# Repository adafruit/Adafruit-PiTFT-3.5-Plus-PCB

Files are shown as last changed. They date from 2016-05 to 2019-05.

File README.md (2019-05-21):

## Adafruit PiTFT 3.5 Plus Display PCB
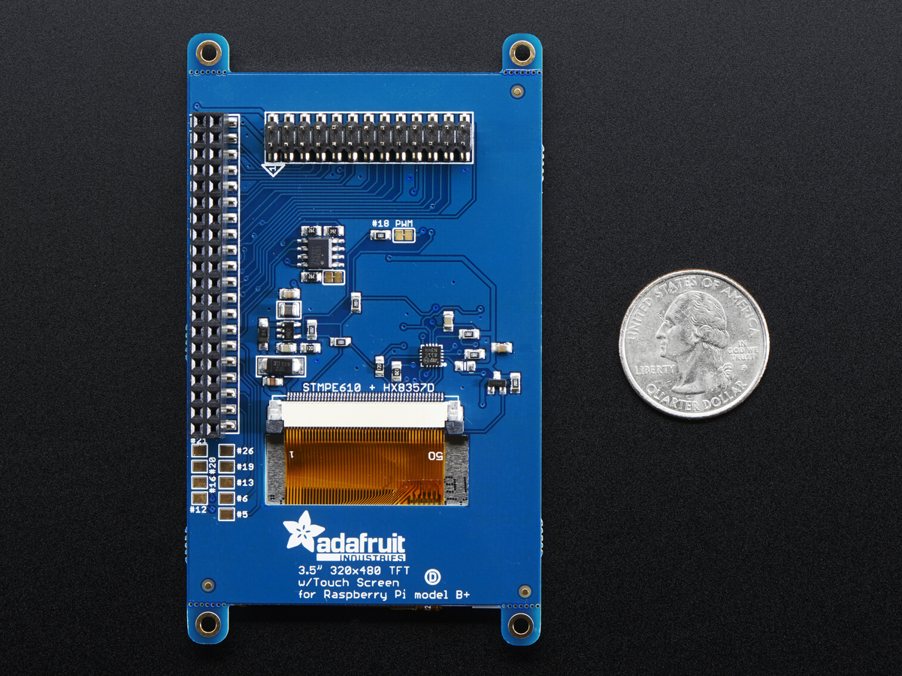
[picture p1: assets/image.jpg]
<a href="http://www.adafruit.com/products/2441"><br/>
Click here to purchase one from the Adafruit shop</a>

This display for the Raspberry Pi features a 3.5" display with 480x320 16-bit color pixels and a resistive touch overlay just like our popular original, but this one is engineered specifically to work with the newer "2x20 connector" Raspberry Pi's. The plate uses the high speed SPI interface on the Pi and can use the mini display as a console, X window port, displaying images or video etc. Best of all it plugs right in on top!

This PiTFT 3.5" is designed to fit nicely onto the Raspberry Pi Zero, Pi 3, Pi 2 or Model A+ / B+ (any Pi with a 2x20 connector). Not for use with an old Pi 1 with 2x13 connector If you'd like to use a 3.5" display with the original Pi A or Pi B, check out this version

PCB files for the Adafruit PiTFT 3.5" Plus. The format is EagleCAD schematic and board layout
- https://www.adafruit.com/product/2441

### License

Adafruit invests time and resources providing this open source design, please support Adafruit and open-source hardware by purchasing products from [Adafruit](https://www.adafruit.com)!

All text above must be included in any redistribution

Designed by Limor Fried/Ladyada for Adafruit Industries.
Creative Commons Attribution/Share-Alike, all text above must be included in any redistribution. 
See license.txt for additional information.

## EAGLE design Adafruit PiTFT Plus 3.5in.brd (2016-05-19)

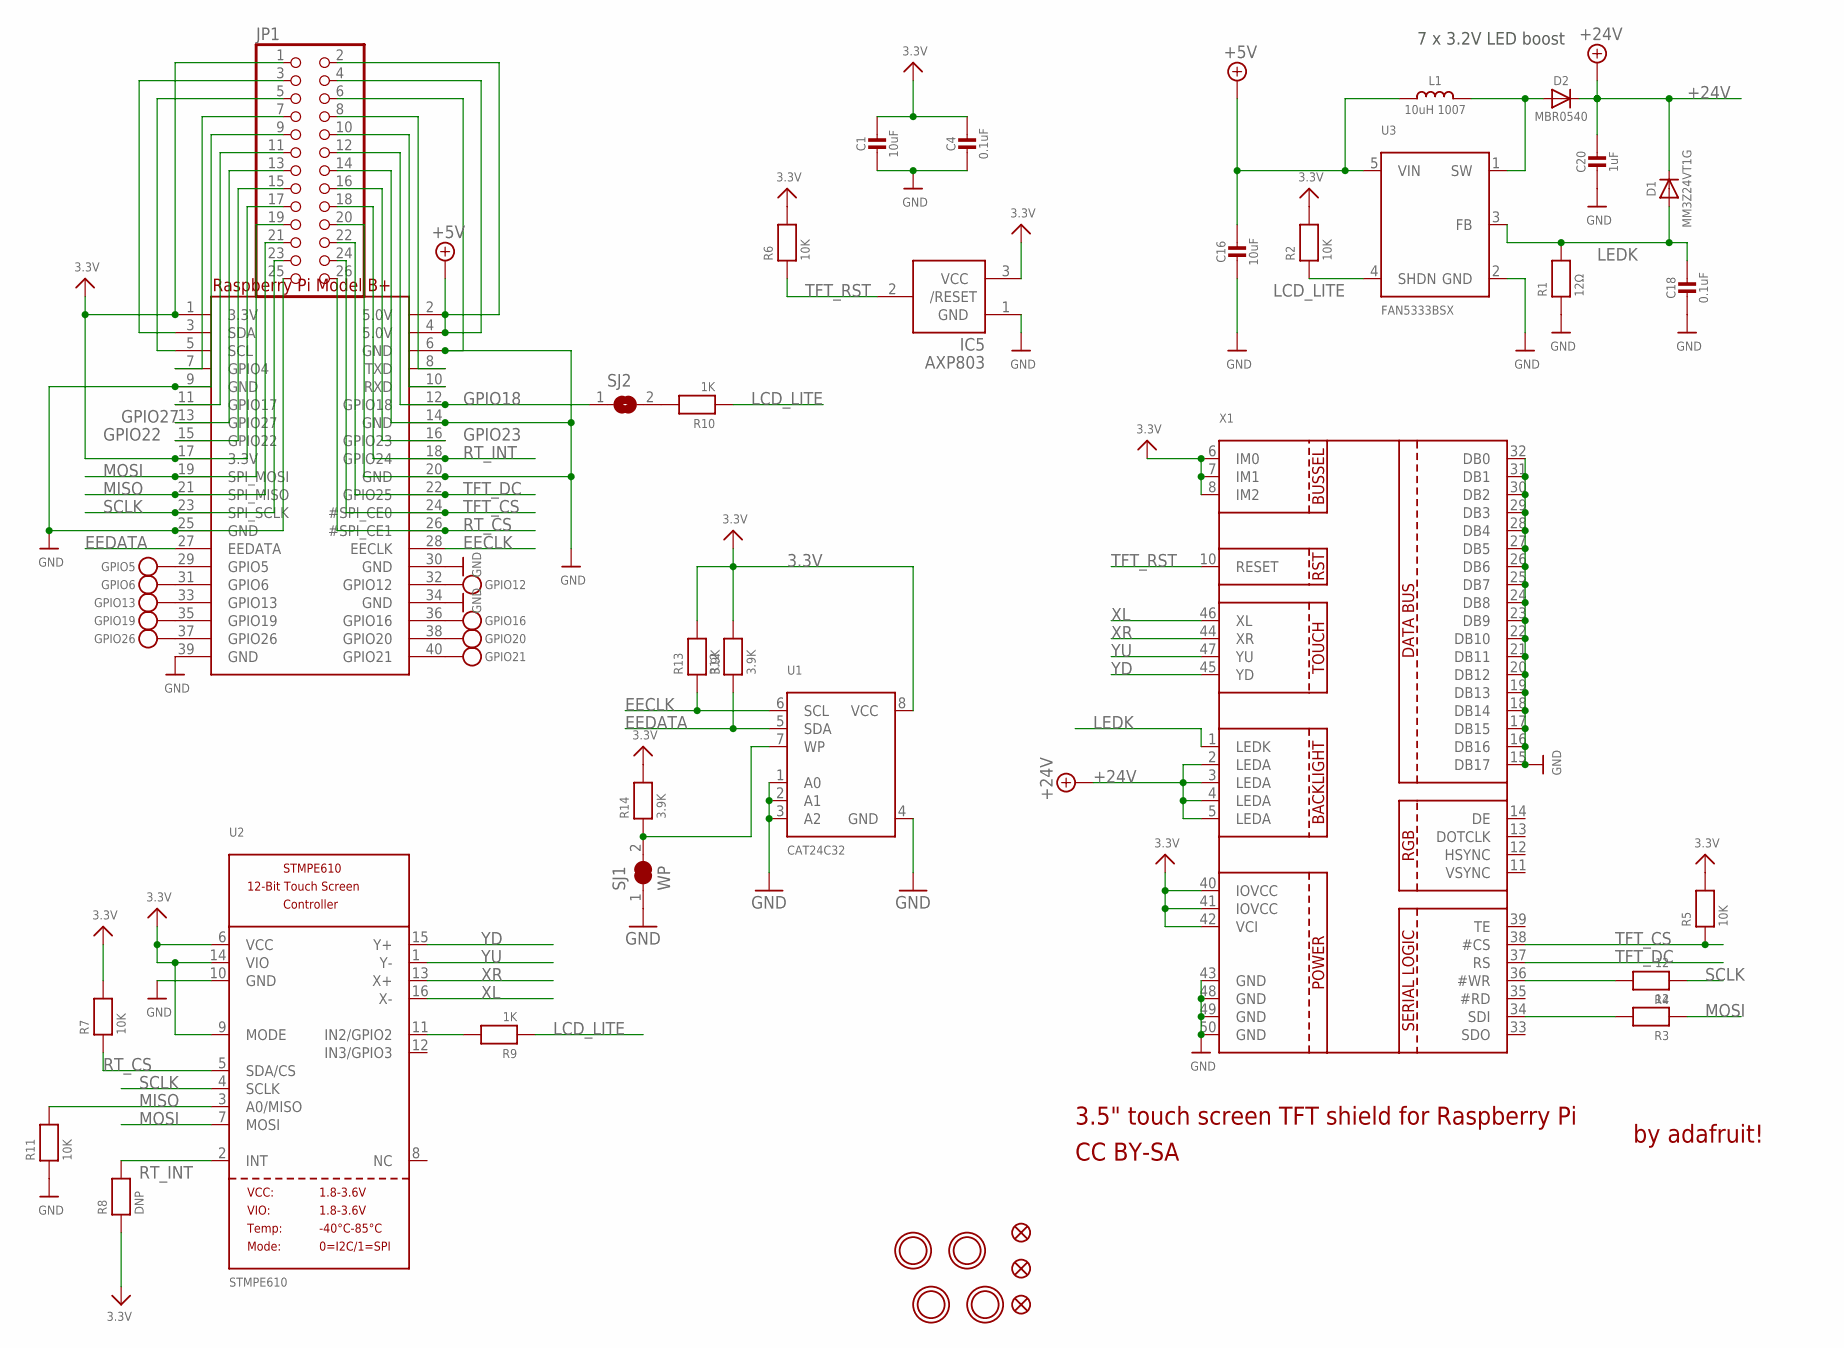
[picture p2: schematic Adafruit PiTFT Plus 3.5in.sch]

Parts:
C1, C16: 10uF; 0805-NO
C4, C18: 0.1uF; 0805-NO
C20: 1uF; _0805MP
D1: MM3Z24VT1G; SMADIODE
D2: MBR0540; SOD-123
GPIO5, GPIO6, GPIO12, GPIO13, GPIO16, GPIO19, GPIO20, GPIO21, GPIO26: TESTPOINT1.5X2.0MM_NOCREAM; PAD-1.5X2.0
IC5: AXP803; SOT23
JP1: HEADER-2X13-SMT; 2X13_SMT_MALE
L1: 10uH 1007; INDUCTOR_1007
R1: 12Ω; 0805-NO
R2, R5, R6, R7, R11: 10K; 0805-NO
R3: 12; _0805MP
R4: 12; 0805-NO
R8: DNP; 0805-NO
R9: 1K; _0805MP
R10: 1K; 0805-NO
R12, R13, R14: 3.9K; 0805-NO
RPI1: RASPBERRYPI_BPLUS_SMT; RASPBERRYPI_BPLUS_SHIELD_SMT
SJ1: WP; SOLDERJUMPER_CLOSEDWIRE
SJ2: SOLDERJUMPERCLOSED; SOLDERJUMPER_CLOSEDWIRE
U1: CAT24C32; SOIC8_150MIL
U2: STMPE610; QFN16_3MM
U3: FAN5333BSX; SOT23-5@1
U$10, U$11, U$18: FIDUCIAL""; FIDUCIAL_1MM
U$15, U$16, U$17, U$20: MOUNTINGHOLE2.5_THICK; MOUNTINGHOLE_2.5_PLATED_THICK
X1: DISP_LCD_3.5IN_320X480_50PIN; TFT_3.5IN_320X480_50PIN

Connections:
3.3V: C1.1, C4.1, IC5.3 (VCC), JP1.1, JP1.17, R2.2, R5.2, R6.2, R7.2, R8.1, R12.2, R13.2, R14.2, RPI1.1 (3.3V), RPI1.17 (3.3V), U1.8 (VCC), U2.6 (VCC), U2.9 (MODE), U2.14 (VIO), X1.6 (IM0), X1.7 (IM1), X1.8 (IM2), X1.40 (IOVCC), X1.41 (IOVCC), X1.42 (VCI)
+5V: C16.1, JP1.2, JP1.4, L1.P$1 (1), RPI1.2 (5.0V), RPI1.4 (5.0V), U3.5 (VIN)
+24V: C20.1, D1.C, D2.C, X1.2 (LEDA), X1.3 (LEDA), X1.4 (LEDA), X1.5 (LEDA)
EECLK: R13.1, RPI1.28 (EECLK), U1.6 (SCL)
EEDATA: R12.1, RPI1.27 (EEDATA), U1.5 (SDA)
GND: C1.2, C4.2, C16.2, C18.2, C20.2, IC5.1 (GND), JP1.6, JP1.9, JP1.14, JP1.20, JP1.25, R1.1, R11.1, RPI1.6 (GND), RPI1.9 (GND), RPI1.14 (GND), RPI1.20 (GND), RPI1.25 (GND), RPI1.30 (GND), RPI1.34 (GND), RPI1.39 (GND), SJ1.1, U1.1 (A0), U1.2 (A1), U1.3 (A2), U1.4 (GND), U2.10 (GND), U3.2 (GND), X1.15 (DB17), X1.16 (DB16), X1.17 (DB15), X1.18 (DB14), X1.19 (DB13), X1.20 (DB12), X1.21 (DB11), X1.22 (DB10), X1.23 (DB9), X1.24 (DB8), X1.25 (DB7), X1.26 (DB6), X1.27 (DB5), X1.28 (DB4), X1.29 (DB3), X1.30 (DB2), X1.31 (DB1), X1.32 (DB0), X1.43 (GND), X1.48 (GND), X1.49 (GND), X1.50 (GND)
GPIO6: GPIO6.P$1, RPI1.31 (GPIO6)
GPIO16: GPIO16.P$1, RPI1.36 (GPIO16)
GPIO18: JP1.12, RPI1.12 (GPIO18), SJ2.1
GPIO22: JP1.15, RPI1.15 (GPIO22)
GPIO23: JP1.16, RPI1.16 (GPIO23)
GPIO27: JP1.13, RPI1.13 (GPIO27)
LCD_LITE: R2.1, R9.1, R10.1, U3.4 (SHDN)
LEDK: C18.1, D1.A, R1.2, U3.3 (FB), X1.1 (LEDK)
MISO: JP1.21, R11.2, RPI1.21 (SPI_MISO), U2.3 (A0/MISO)
MOSI: JP1.19, R3.1, RPI1.19 (SPI_MOSI), U2.7 (MOSI)
unnamed: R4.2, X1.36 (#WR)
unnamed: R3.2, X1.34 (SDI)
unnamed: R9.2, U2.11 (IN2/GPIO2)
unnamed: R10.2, SJ2.2
unnamed: GPIO5.P$1, RPI1.29 (GPIO5)
unnamed: JP1.3, RPI1.3 (SDA)
unnamed: JP1.5, RPI1.5 (SCL)
unnamed: JP1.7, RPI1.7 (GPIO4)
unnamed: GPIO13.P$1, RPI1.33 (GPIO13)
unnamed: GPIO19.P$1, RPI1.35 (GPIO19)
unnamed: JP1.11, RPI1.11 (GPIO17)
unnamed: D2.A, L1.P$2 (2), U3.1 (SW)
unnamed: GPIO26.P$1, RPI1.37 (GPIO26)
unnamed: GPIO12.P$1, RPI1.32 (GPIO12)
unnamed: GPIO20.P$1, RPI1.38 (GPIO20)
unnamed: R14.1, SJ1.2, U1.7 (WP)
unnamed: JP1.10, RPI1.10 (RXD)
unnamed: JP1.8, RPI1.8 (TXD)
unnamed: GPIO21.P$1, RPI1.40 (GPIO21)
RT_CS: JP1.26, R7.1, RPI1.26 (#SPI_CE1), U2.5 (SDA/CS)
RT_INT: JP1.18, R8.2, RPI1.18 (GPIO24), U2.2 (INT)
SCLK: JP1.23, R4.1, RPI1.23 (SPI_SCLK), U2.4 (SCLK)
TFT_CS: JP1.24, R5.1, RPI1.24 (#SPI_CE0), X1.38 (#CS)
TFT_DC: JP1.22, RPI1.22 (GPIO25), X1.37 (RS)
TFT_RST: IC5.2 (/RESET), R6.1, X1.10 (RESET)
XL: U2.16 (X-), X1.46 (XL)
XR: U2.13 (X+), X1.44 (XR)
YD: U2.15 (Y+), X1.45 (YD)
YU: U2.1 (Y-), X1.47 (YU)

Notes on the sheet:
3.5" touch screen TFT shield for Raspberry Pi
by adafruit!
CC BY-SA
7 x 3.2V LED boost

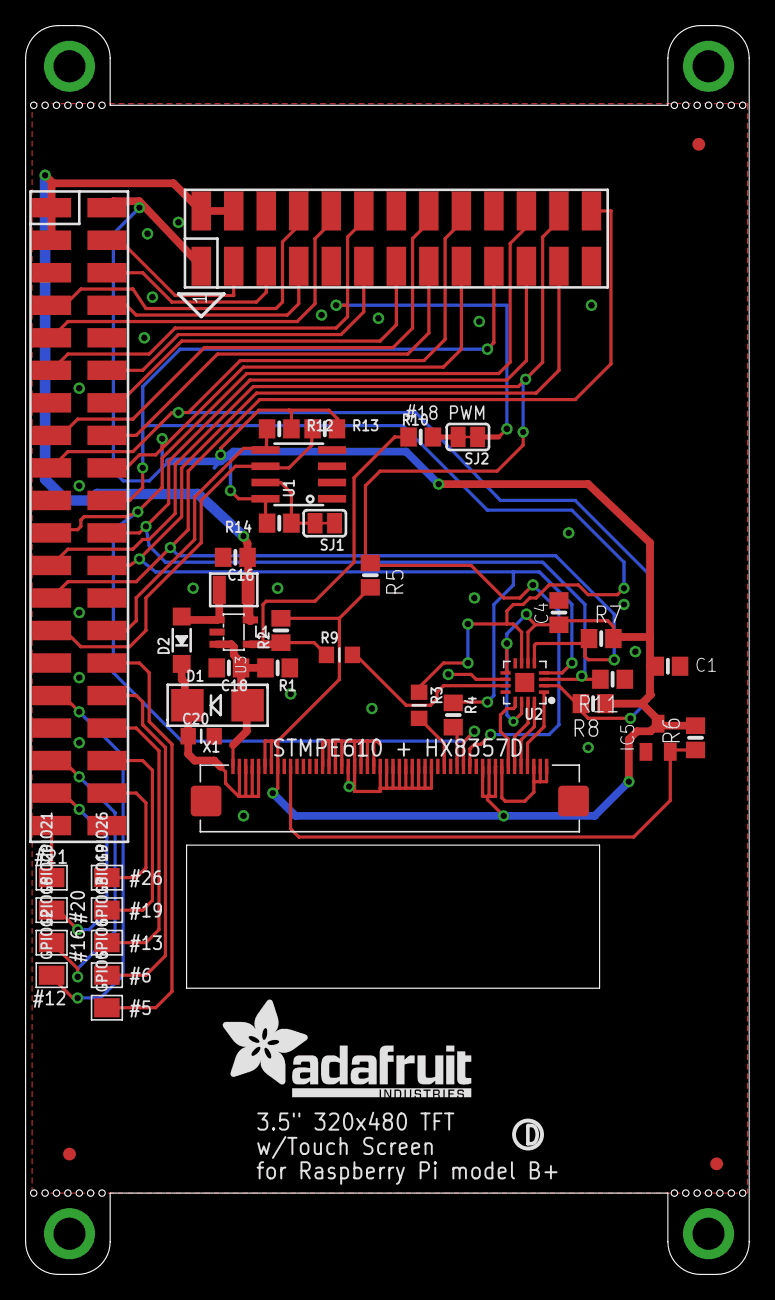
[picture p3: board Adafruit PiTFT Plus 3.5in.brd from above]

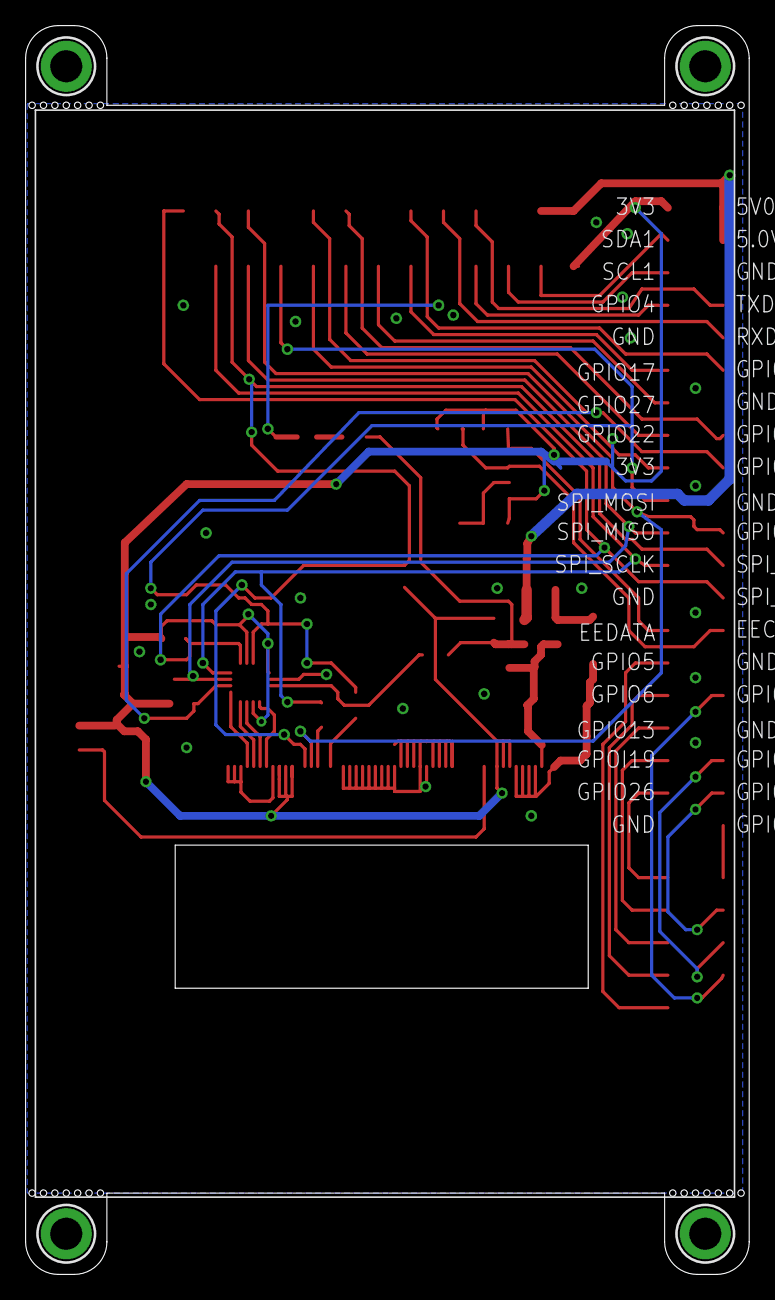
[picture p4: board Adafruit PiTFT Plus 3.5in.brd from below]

Board: 2 copper layers, 56.5 x 97.5 mm, 49 parts (6 on the bottom side), 45 nets.

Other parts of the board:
U$19: PCBFEAT-REV-056
U$23: ADAFRUIT_TEXT_20MM

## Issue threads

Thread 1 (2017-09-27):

Jessie-based PiTFT 3.5 image is unusable on Windows 7

mikechabot, 2017-09-27:
I clicked "Download Jessie-based PiTFT 3.5" Resistive Image for Pi 1, Pi 2 and Pi 3 (Sept 23, 2016 image, made Nov 10)" via [the easy install](https://learn.adafruit.com/adafruit-pitft-3-dot-5-touch-screen-for-raspberry-pi/easy-install), however, I can't unzip since the uncompressed file size is > 700 Petabytes.

What is happening here?

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

ladyada, 2017-09-27:
try burning it with Etcher, don't uncompress!

Closed 2017-09-27.
